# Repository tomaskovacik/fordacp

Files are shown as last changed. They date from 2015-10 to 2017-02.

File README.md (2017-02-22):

SW is Dale Thomas/Krzysztof Pintscher/Andrew Hammond work not my

www.instructables.com/id/Ford-CD-Emulator-Arduino-Mega/
http://www.instructables.com/id/Ford-Bluetooth-Interface-Control-phone-with-stock-/

I make just HW part in kicad, libraries for BLK-MD-SPK-B and S3860M-S <a href="https://github.com/tomaskovacik/hw/tree/master/kicad/library">here</a>

work in progress

untested

<a href="http://kovo-blog.blogspot.sk/2015/01/breadboard-adapter-for-blk-md-spk-b.html">BLK-MD-SPK-B</a> module support.
<a href="http://kovo-blog.blogspot.sk/2015/06/xs3868-breadbord-adapter.html">S3860M-S</a> module support.

schematics
------------
<a href="https://github.com/tomaskovacik/fordacp/raw/master/hw/schematics.pdf">schematics in pdf</a>

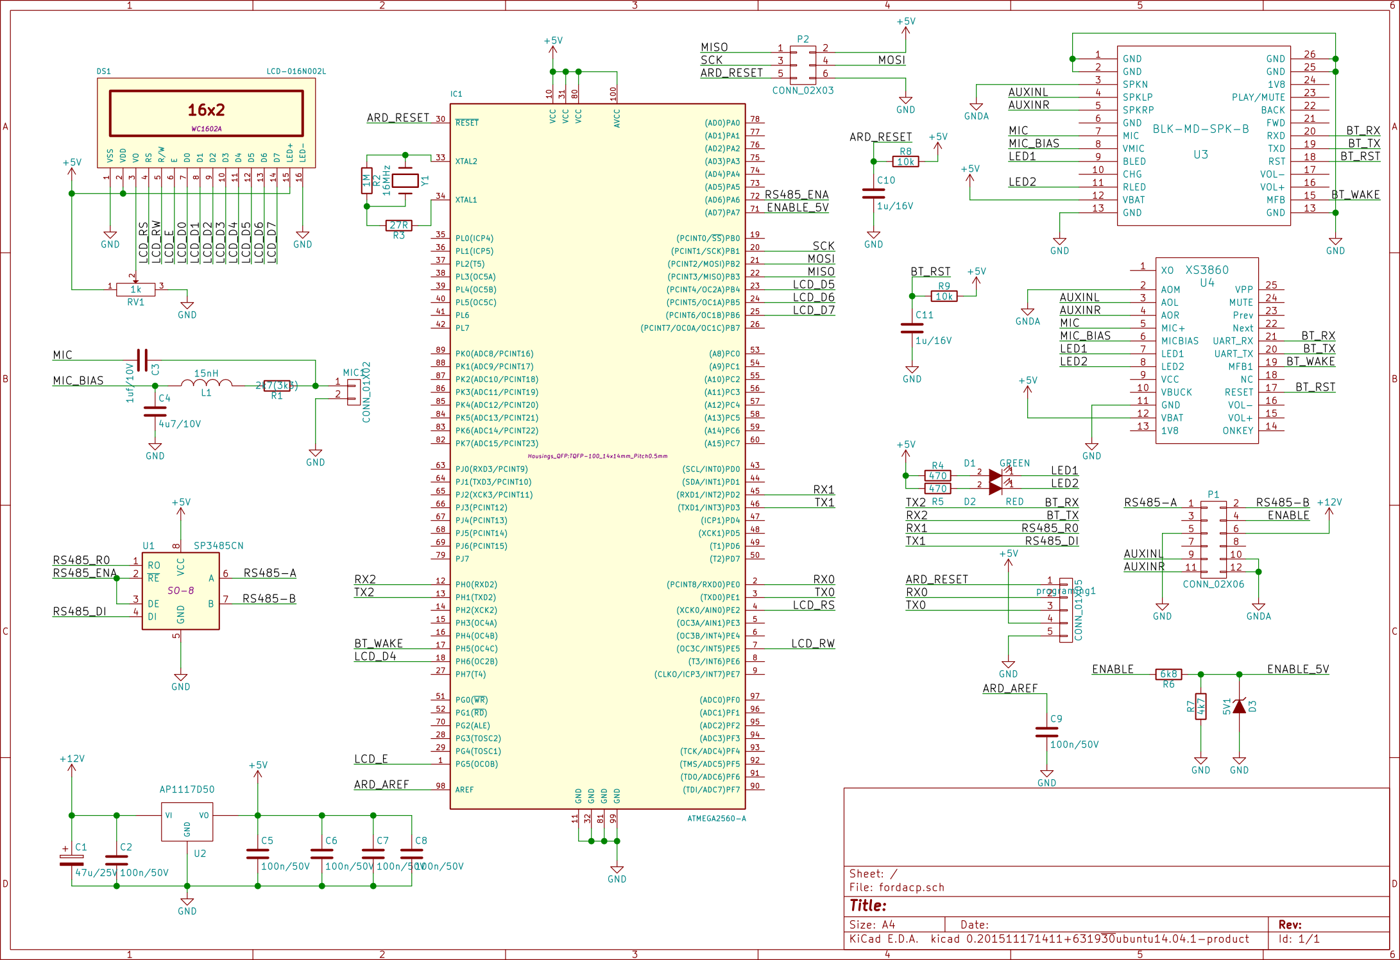
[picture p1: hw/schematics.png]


3d render
---------

with LCD

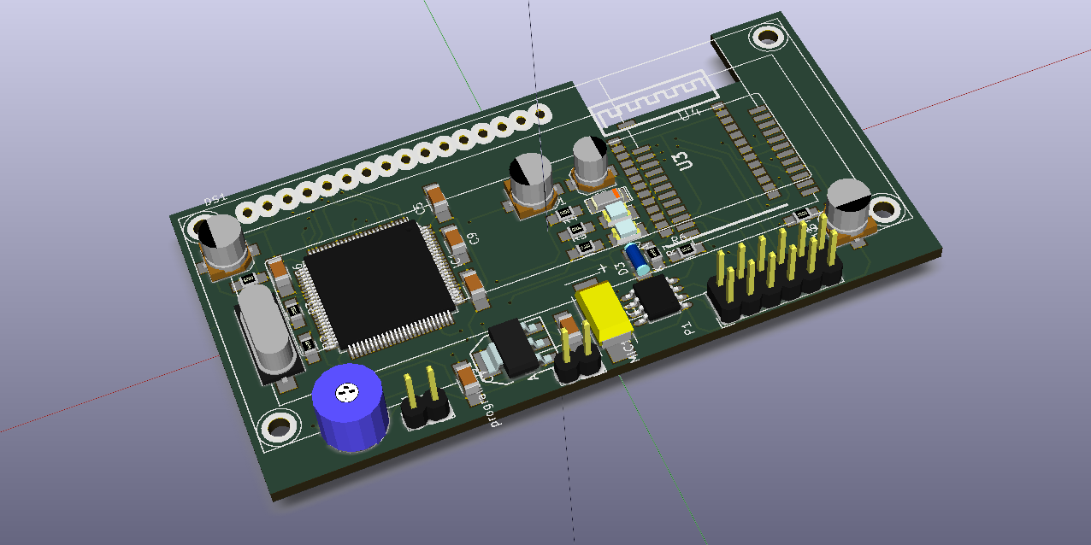
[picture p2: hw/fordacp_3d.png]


without LCD

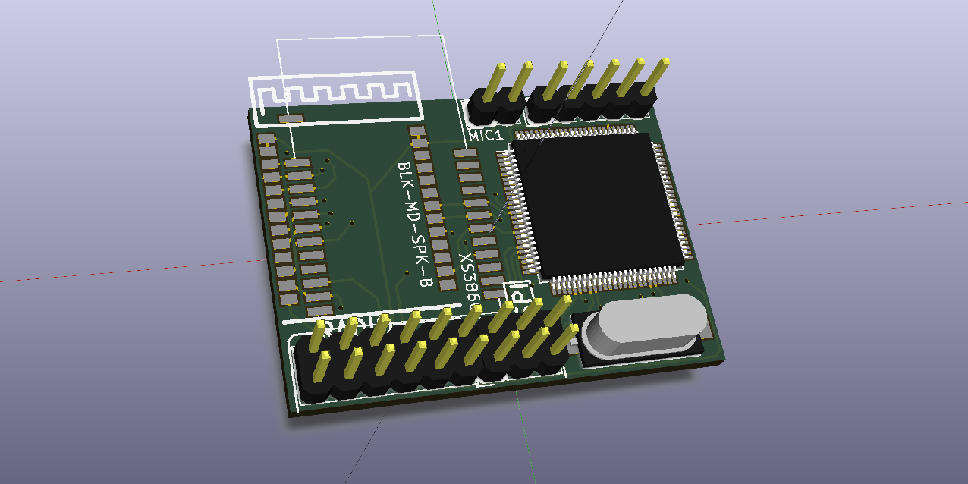
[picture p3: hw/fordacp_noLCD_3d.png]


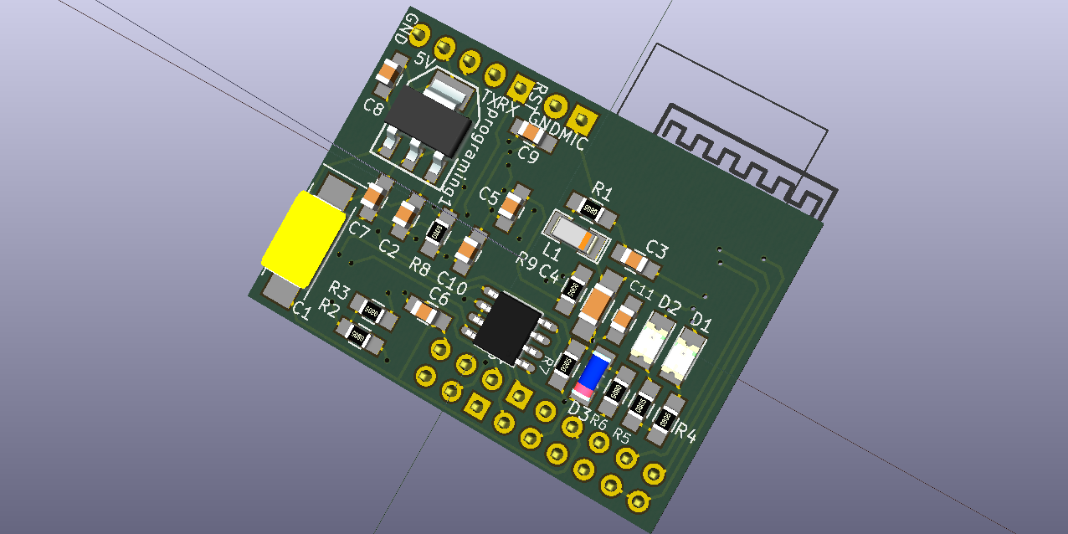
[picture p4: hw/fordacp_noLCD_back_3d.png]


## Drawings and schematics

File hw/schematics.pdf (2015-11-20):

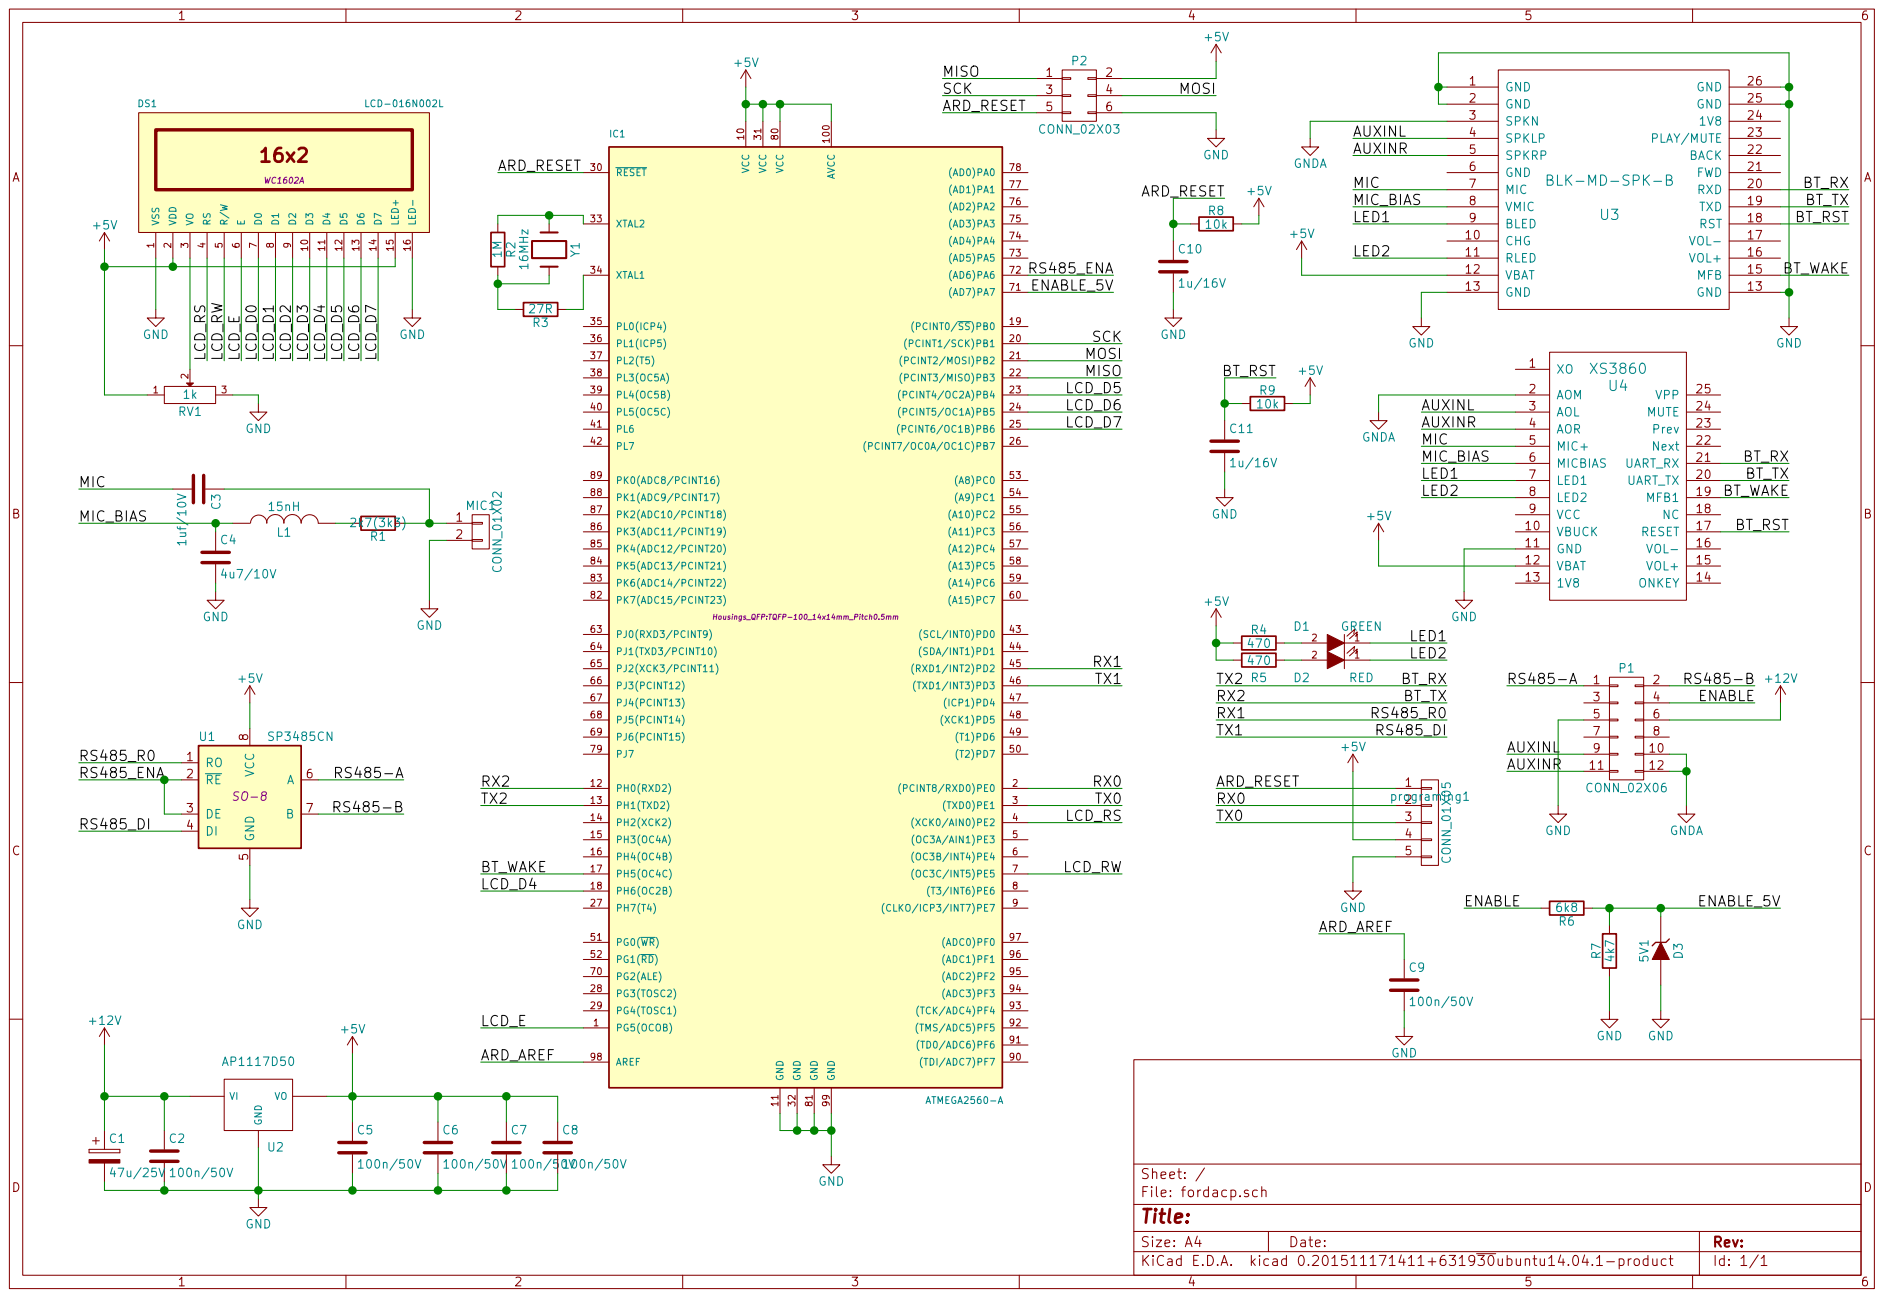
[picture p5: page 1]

PL2(T5) 37 | MOSI
PL3(OC5A) 38 | MISO

File: fordacp.sch Sheet: /
Id: 1/1 Title:

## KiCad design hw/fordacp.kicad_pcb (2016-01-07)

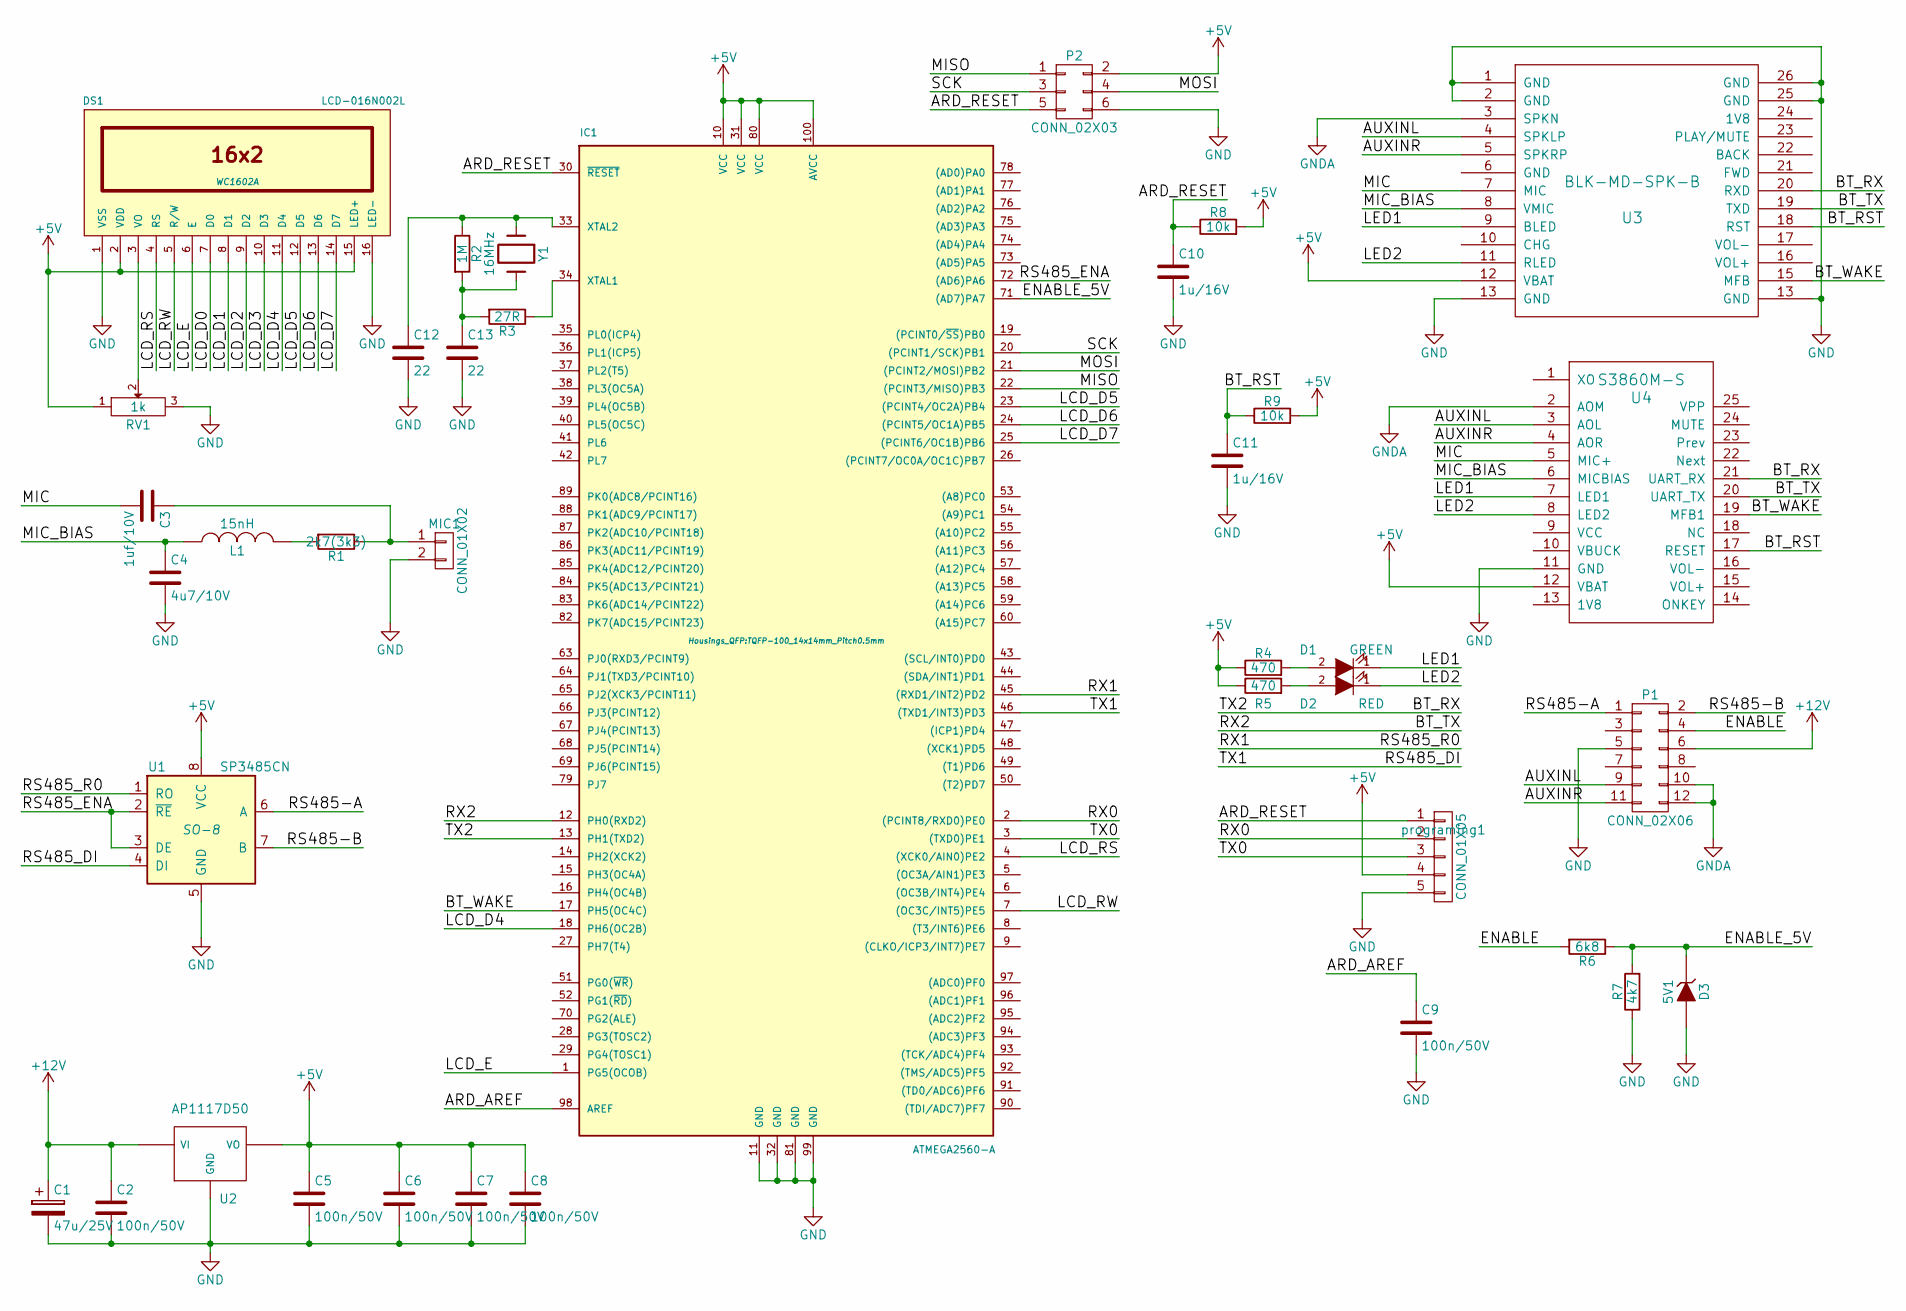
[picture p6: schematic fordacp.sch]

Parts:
C1: 47u/25V; TantalC_SizeD_EIA-7343_HandSoldering
C2, C5, C6, C7, C8, C9: 100n/50V; C_0805_HandSoldering
C3: 1uf/10V; C_0805_HandSoldering
C4: 4u7/10V; C_1206_HandSoldering
C10, C11: 1u/16V; C_0805_HandSoldering
C12, C13: 22; C_0805
D1: GREEN; LED-1206
D2: RED; LED-1206
D3: 5V1; MiniMELF_Standard
DS1: LCD-016N002L; WC1602A
IC1: ATMEGA2560-A; TQFP-100_14x14mm_Pitch0.5mm
L1: 15nH; SMD-1206_Pol
MIC1: CONN_01X02; Pin_Header_Straight_1x02
P1: CONN_02X06; Pin_Header_Straight_2x06
P2: CONN_02X03; Pin_Header_Straight_2x03
R1: 2k7(3k3); R_0805_HandSoldering
R2: 1M; R_0805_HandSoldering
R3: 27R; R_0805_HandSoldering
R4, R5: 470; R_0805_HandSoldering
R6: 6k8; R_0805_HandSoldering
R7: 4k7; R_0805_HandSoldering
R8, R9: 10k; R_0805_HandSoldering
RV1: 1k; Potentiometer_Bourns_3339H_Angular_ScrewUp
U1: SP3485CN; SO-8
U2: AP1117D50; SOT-223-REGULATOR
U3: BLK-MD-SPK-B
U4: S3860M-S
Y1: 16MHz; Q_49U3HMS
programing1: CONN_01X05; Pin_Header_Straight_1x05

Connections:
+5V: C5.1, C6.1, C7.1, C8.1, DS1.2 (VDD), DS1.15 (LED+), IC1.10 (VCC), IC1.31 (VCC), IC1.80 (VCC), IC1.100 (AVCC), P2.2, R4.1, R5.1, R8.2, R9.2, RV1.1, U1.8 (VCC), U2.VO, U3.12 (VBAT), U4.12 (VBAT), programing1.4
+12V: C1.1, C2.1, P1.6, U2.VI
/ARD_AREF: C9.1, IC1.98 (AREF)
/ARD_RESET: C10.1, IC1.30 (~RESET), P2.5, R8.1, programing1.1
/AUXINL: P1.9, U3.4 (SPKLP), U4.3 (AOL)
/AUXINR: P1.11, U3.5 (SPKRP), U4.4 (AOR)
/BT_RST: C11.1, R9.1, U3.18 (RST), U4.17 (RESET)
/BT_RX: IC1.13 (PH1(TXD2)), U3.20 (RXD), U4.21 (UART_RX)
/BT_TX: IC1.12 (PH0(RXD2)), U3.19 (TXD), U4.20 (UART_TX)
/BT_WAKE: IC1.17 (PH5(OC4C)), U3.15 (MFB), U4.19 (MFB1)
/ENABLE: P1.4, R6.2
/ENABLE_5V: D3.1 (K), IC1.71 ((AD7)PA7), R6.1, R7.2
/LCD_D4: DS1.11 (D4), IC1.18 (PH6(OC2B))
/LCD_D5: DS1.12 (D5), IC1.23 ((PCINT4/OC2A)PB4)
/LCD_D6: DS1.13 (D6), IC1.24 ((PCINT5/OC1A)PB5)
/LCD_D7: DS1.14 (D7), IC1.25 ((PCINT6/OC1B)PB6)
/LCD_E: DS1.6 (E), IC1.1 (PG5(OCOB))
/LCD_RS: DS1.4 (RS), IC1.4 ((XCK0/AIN0)PE2)
/LCD_RW: DS1.5 (R/W), IC1.7 ((OC3C/INT5)PE5)
/LED1: D1.1 (K), U3.9 (BLED), U4.7 (LED1)
/LED2: D2.1 (K), U3.11 (RLED), U4.8 (LED2)
/MIC: C3.2, U3.7 (MIC), U4.5 (MIC+)
/MIC_BIAS: C4.1, L1.1, U3.8 (VMIC), U4.6 (MICBIAS)
/MISO: IC1.22 ((PCINT3/MISO)PB3), P2.1
/MOSI: IC1.21 ((PCINT2/MOSI)PB2), P2.4
/RS485-A: P1.1, U1.6 (A)
/RS485-B: P1.2, U1.7 (B)
/RS485_DI: IC1.46 ((TXD1/INT3)PD3), U1.4 (DI)
/RS485_ENA: IC1.72 ((AD6)PA6), U1.2 (~RE~), U1.3 (DE)
/RS485_R0: IC1.45 ((RXD1/INT2)PD2), U1.1 (RO)
/RX0: IC1.2 ((PCINT8/RXD0)PE0), programing1.2
/SCK: IC1.20 ((PCINT1/SCK)PB1), P2.3
/TX0: IC1.3 ((TXD0)PE1), programing1.3
GND: C1.2, C2.2, C4.2, C5.2, C6.2, C7.2, C8.2, C9.2, C10.2, C11.2, C12.2, C13.2, D3.2 (A), DS1.1 (VSS), DS1.16 (LED-), IC1.11 (GND), IC1.32 (GND), IC1.81 (GND), IC1.99 (GND), MIC1.2, P1.5, P2.6, R7.1, RV1.3, U1.5 (GND), U2.GND, U3.1 (GND), U3.2 (GND), U3.13 (GND), U3.25 (GND), U3.26 (GND), U4.11 (GND), programing1.5
GNDA: P1.10, P1.12, U3.3 (SPKN), U4.2 (AOM)
unnamed: C3.1, MIC1.1, R1.1
unnamed: C12.1, IC1.33 (XTAL2), R2.1, Y1.1
unnamed: C13.1, R2.2, R3.2, Y1.2
unnamed: D1.2 (A), R4.2
unnamed: D2.2 (A), R5.2
unnamed: DS1.3 (VO), RV1.2
unnamed: IC1.34 (XTAL1), R3.1
unnamed: L1.2, R1.2

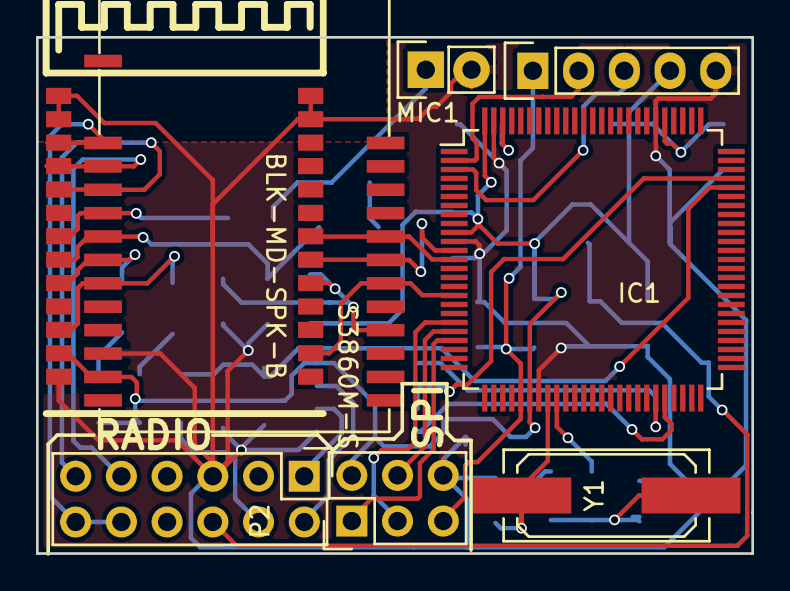
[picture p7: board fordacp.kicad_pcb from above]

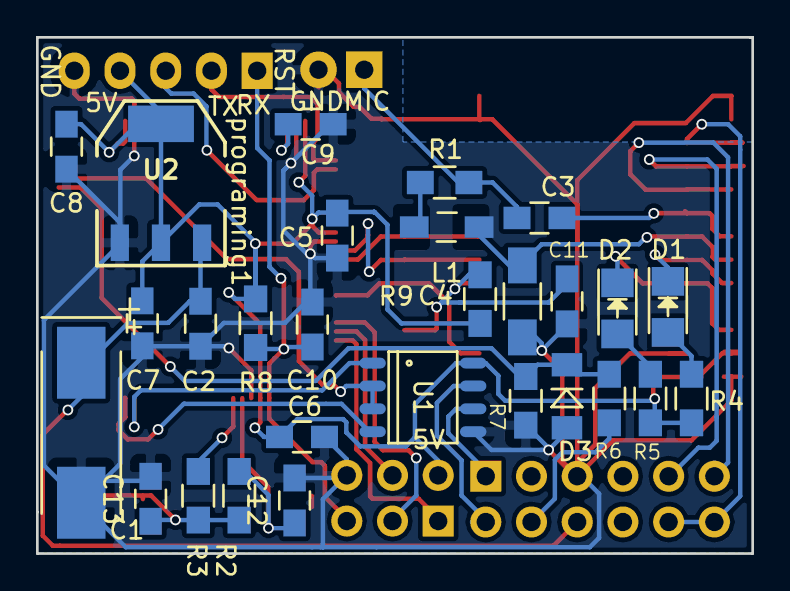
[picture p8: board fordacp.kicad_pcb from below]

Board: 2 copper layers, 39.7 x 28.7 mm, 36 parts (28 on the bottom side), 35 nets.

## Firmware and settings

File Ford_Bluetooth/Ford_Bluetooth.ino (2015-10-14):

/* 
 * Ford Head Unit to Bluetooth Interface V 1.0
 *
 * The code in this file is intended to be uploaded to an Arduino Mega2560
 * used in combination with a specialized shield that contains the hardware
 * needed to interface with a Ford head unit and bluetooth module.
 *
 * Compatible Ford Head Units: Any unit that uses ACP (Automotive Communication
 *                             Protocol) and has a connector for a CD changer.
 *
 *                             Info on ACP:
 *                             http://www.mictronics.de/projects/cdc-protocols/#FordACP
 *                             
 *                             Some examples are:
 *                             4050RDS, 4500, 4600RDS, 5000RDS, 5000RDS EON, 
 *                             6000CD RDS, 6000 MP3, 7000RDS
 *
 *                             These are all head units from the '96 - '05 era.
 *
 *                             The unit used during testing is a 1W1F-18C870-DA 02 03
 *                             from a '99 Ford Expedition.
 *
 * Bluetooth Module: OVC3860 on one of two breakout boards.
 *                   The XS3868 or BLK-MD-SPK-B.
 *
 * The code for the ACP protocol was originally written by Andrew Hammond for his Yampp
 * and was ported over to the Arduino platform by Krzysztof Pintscher. Please see the 
 * ACP and CD headers for more info.
 *
 **************************************************************************************
 * Revisions:
 *
 * 2014-11-30 version 1.0 - public release
 *
 **************************************************************************************
 * Requirements:
 *
 * -LiquidCrystal library
 * -TimerOne library
 * -TimerThree library
 *
 **************************************************************************************
 * TODO:
 *
 * -remove lcd code unless it proves useful for something other than debug
 * -add code to automatically change and save the name of the OVC (Ford Bluetooth?)
 *
 */
 
#include <LiquidCrystal.h>
#include <util/delay.h>
#include <TimerOne.h>
#include <TimerThree.h>

typedef unsigned char u08;
typedef unsigned short u16;
typedef unsigned long  u32;

#ifndef cbi // "clear bit"
 #define cbi(sfr, bit) (_SFR_BYTE(sfr) &= ~_BV(bit))
#endif
#ifndef sbi // "set bit"
 #define sbi(sfr, bit) (_SFR_BYTE(sfr) |= _BV(bit))
#endif
#define outp(VAL,ADRESS) ((ADRESS) = (VAL))
#define inp(VAL) (VAL)

#define ACP_UART_BAUD_RATE 	9600
#define ACP_UART_BAUD_SELECT ((u32)((u32)16000000/(ACP_UART_BAUD_RATE*16L)-1))
#define AT_UART_BAUD_RATE 	115200
#define AT_UART_BAUD_SELECT ((u32)((u32)16000000/(AT_UART_BAUD_RATE*8L)-1))
#define ACP_LISTEN 0
#define ACP_SENDACK 1
#define ACP_MSGREADY 2
#define ACP_WAITACK 3
#define ACP_SENDING 4 
#define HU_EV_STOP 1
#define HU_EV_CANCEL_VOICE_CALL 9

const int switchPin = 28; // Pin 28 connected to pins 2 & 3 (RE/DE) on MAX485
const int audioOnPin = 29; // Pin 29 connected to "Audio On" pin from head unit
const int wakePin = 8; // pin 8 connected to MFB pin of OVC
int audioOnState = 0;
int lastAudioPinState = 2;

LiquidCrystal lcd(2, 3, 4, 9, 10, 11, 12);
int c = 0; // used for lcd debug

uint8_t acp_rx[12];
uint8_t acp_tx[12];
uint8_t acp_rxindex;
uint8_t acp_txindex;
u08 acp_status;
u08 acp_txsize;
u08 acp_timeout;
u08 acp_checksum;
u08 acp_retries;
u08 acp_mode;
uint16_t acp_ltimeout;
boolean vCall = false;
boolean rewindState = false;
boolean ffState = false;
boolean callStatus = false;
boolean wPlayTime = false;
int currentTrack = 1;
boolean reset_timer = false;

uint8_t at_tx[8];
uint8_t at_rx[9];
uint8_t at_rxindex = 0;
u08 at_checksum;
u08 at_txsize = 8;
u08 at_rxsize = 9;

void setup(){
  
  lcd.begin(16,2);//specify screen dimensions
  lcd.clear();//clear the screen
  lcd.setCursor(0,0); // set cursor to col 0 row 0
  lcd.print("OVC3868");// print from cursor location TODO: get name of blutooth module (see above)
  
  pinMode(wakePin, OUTPUT);
  digitalWrite(wakePin, LOW);
  pinMode(audioOnPin, INPUT);
  outp(0xff, PORTD);
  outp(0xC0, DDRD);
  pinMode(switchPin, OUTPUT);
  digitalWrite(switchPin, LOW);
  delay(500);
  acp_uart_init(ACP_UART_BAUD_SELECT); // Initialize the ACP USART
  at_uart_init(AT_UART_BAUD_SELECT); // Initialize the AT USART
  delay(1);
}

void disconnectBluetooth() { // messages required to disconnect the OVC
     at_process(16); // Disconnect Audio Source
     at_process(3);  // Disconnect hshf
     at_process(6);  // Enter Pairing
}

void wakeOVC() // 16.5ms pulse required to wake the OVC
{
  digitalWrite(wakePin, HIGH); 
  delay(1100);
  digitalWrite(wakePin, LOW);
}

void loop()
{
  audioOnState = digitalRead(audioOnPin); // monitor the "Audio On" signal
  if(audioOnState != lastAudioPinState){
   if (audioOnState == 0) {
     Timer1.detachInterrupt(); // stop sending ACP messages
     Timer3.initialize(3000000); // start sending disconnect messages to OVC
     Timer3.attachInterrupt(disconnectBluetooth);
   }
   if (audioOnState == 1) {
    Timer3.detachInterrupt(); // stop sending disconnect messages to OVC
   }
  } 
  lastAudioPinState = audioOnState; 
  acp_handler();  
}

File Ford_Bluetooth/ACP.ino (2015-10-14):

/*
 * Original code for Yampp -  Andrew Hammond <andyh@mindcode.co.uk>
 *
 * For Arduino Mega 2560 - Krzysztof Pintscher <niou.ns@gmail.com>
 * Full schematics and connection by Krzysztof Pintscher
 * please keep our credits in header :)
 *
 * Integration with AT Commands for OVC3868 - Dale Thomas <dalethomas@me.com>
 *
 ******************************************************************
 * Revisions:
 *
 * 2013-12-17 version 0.9 - public relase
 * 2014-11-30 version 1.0 - Annotations and integration with AT file -DT
 *
 */
void acp_uart_init(unsigned short baud)
{
  cli();
  outp((u08)(baud>>8), UBRR1H);                  
  outp((u08)baud, UBRR1L);
  sbi(UCSR1B, RXEN1);  // Receiver enable
  sbi(UCSR1B, TXEN1);  // Transmitter enable
  sbi(UCSR1B, RXCIE1); // RX complete interrupt enable
  cbi(UCSR1B, UDRIE1); // USART data register empty complete enable
  sbi(UCSR1B, UCSZ12); // Character size n (setting this to one enables 9-bit character data)
  sei();
 }


SIGNAL(USART1_RX_vect)
{
  u08 eod = (inp(UCSR1B) & _BV(RXB81));
  uint8_t ch = inp(UDR1); 
  
  if (acp_status != ACP_LISTEN)return; // ignore incoming msgs if busy processing
  if(!eod)acp_checksum += ch;
  acp_rx[acp_rxindex++] = ch;
  if(acp_rxindex>12)acp_reset();
  else if (eod)	
  {
    if (acp_checksum == ch)      // Valid ACP message - send ack
    {              
      acp_status=ACP_SENDACK;
      acp_handler();
    }
    else acp_reset();		// Abort message
  }
  return; 
}


 void acp_txenable(boolean enable)
{
  if (enable)PORTA |= (1<<PA6); //sets a high state on pin PD4
  else PORTA &= ~(1<<PA6); //sets the low state on pin PD4
  asm volatile("nop");
}


void acp_sendack(void)
{
  while(!(inp(PORTD) & 0x01)) // Wait till RX line goes high (idle)
  cbi(UCSR1B, RXCIE1);
  acp_txenable(true);  
  sbi(UCSR1A, TXC1); // Set TXC to clear it!!
  cbi(UCSR1B, TXB81);
  outp(0x06, UDR1);
  while(!(inp(UCSR1A) & _BV(TXC1))); // wait till buffer clear
  acp_txenable(false);
}


void acp_reset(void)
{
  acp_retries=0;
  acp_timeout=0;
  acp_checksum=0;
  acp_rxindex=0;
  acp_txindex=0;
  acp_txsize=0;
  acp_status=ACP_LISTEN;
}


void acp_sendmsg(void)
{
  u08 i;
  while(!(inp(PORTD) & 0x01)) // Wait till RX line goes high (idle)
  cbi(UCSR1B, RXCIE1);
  acp_txenable(true);
  _delay_us(104*17);
  for(i=0; i <= acp_txsize; i++)
  {
    while(!(inp(UCSR1A) & _BV(UDRIE1))); // wait till tx buffer empty
    cbi(UCSR1B, TXB81);
    if(i==acp_txsize) 
    {
      sbi(UCSR1A, TXC1);   // set TXC to clear it!
      sbi(UCSR1B, TXB81);  // set 9th bit at end of message
    }
    outp(acp_tx[i], UDR1);
  }
  while(!(inp(UCSR1A) & _BV(TXC1))); // wait till last character tx complete
  acp_txenable(false); // switch back to rx mode immediately
  acp_status = ACP_WAITACK;	// wait for ACK
  sbi(UCSR1B, RXCIE1);
}


void acp_handler()
{
  if (acp_status == ACP_LISTEN)
  {
  if(++acp_ltimeout == 1000)acp_ltimeout=0; 
  }
  if (acp_status == ACP_SENDACK)
  { 
    acp_sendack();
    acp_status=ACP_MSGREADY;
  }
  else if (acp_status == ACP_WAITACK)acp_reset(); // HU does not seem to return an ACK
  if (acp_status == ACP_MSGREADY)
  {
    acp_status = ACP_SENDING;
    acp_process(); // Process message		
  }
  else if (acp_status == ACP_SENDING)
  {
    acp_timeout++;
    if(!acp_timeout)
    {
      acp_reset();
      acp_txenable(false);
    }		
  }
}


void acp_process(void)
{	
  acp_timeout = 0;
  acp_tx[0] = 0x71; // medium/low priority
  acp_tx[1] = 0x9b;
  acp_tx[2] = 0x82; // message from "CD Changer" (bluetooth interface)
  acp_tx[3] = acp_rx[3];

  if (acp_rx[2] == 0x80)  // Message from Head Unit
  {
    if(acp_rx[1]==0x9a || acp_rx[1]==0x9b) // CD Changer functional address 
    {
      switch (acp_rx[3])
      {
      case 0xC8:		// Handshake 3 - CD Changer now recognized
        acp_tx[4] = acp_rx[4];
        acp_chksum_send(5);
        break;

      case 0xFC:		// Handshake 2
        acp_tx[4] = acp_rx[4];
        acp_chksum_send(5);
        break;

      case 0xE0:		// Handshake 1
        acp_tx[4] = 0x04;
        acp_chksum_send(5);
        break;
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

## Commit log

2015-10-14 HW schematics
    [fordacp.kicad_pcb, fordacp.sch]
2015-10-14 pcb first try
    [fordacp.kicad_pcb, fordacp.sch]
2015-10-14 rename hw/fordacp.pdf hw/schematics.pdf
2015-10-15 schematics export to png
2015-10-15 readme update - schematics
2015-10-15 pcb without LCD
    [fordacp_noLCD.kicad_pcb]
2015-10-15 change modules to 1206 for 1u 2u2 4u7 capacitors
    [fordacp.sch]
2015-10-15 update pcb without LCD
    [fordacp_noLCD.kicad_pcb]
2015-11-20 added SPI interface
    [fordacp.sch, fordacp_noLCD.kicad_pcb]
2015-11-20 add SPI schematics file
2015-11-20 add SPI schematics file in pdf
2015-11-20 schematics cleanup
    [fordacp.sch]
2015-12-10 pictures of assembled unit
2015-12-10 L1 better housing
    [fordacp.sch, fordacp_noLCD.kicad_pcb]
2016-01-05 set PCB witout LCD as default
    [fordacp.kicad_pcb, fordacp_LCD.kicad_pcb]
2016-01-05 renam XS3860 to XS3868
    [fordacp.kicad_pcb]
2016-01-11 differential output amplifier with LM358
    [fordacp.sch]
2018-06-05 latest modification, I do not remember what it is ...
    [fordacp.sch]
